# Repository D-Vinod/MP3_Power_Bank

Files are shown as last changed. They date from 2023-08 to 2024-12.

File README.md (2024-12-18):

# 🎵 MP3 Player Design Project

## 📝 Project Overview

This repository contains the design and implementation details of an **MP3 player with power bank functionality**, developed as part of the **EN2160 - Electronic Design Realization** course at the **University of Moratuwa**. The project incorporates multiple features including music playback from an SD card, volume control, an OLED display, and a high-capacity battery pack for extended use and device charging.

---

## 📌 Table of Contents

1. **[Introduction](#introduction)**
2. **[Design Specifications](#design-specifications)**
   - [Display](#display)
   - [Control IC](#control-ic)
   - [SD Card Storage](#sd-card-storage)
   - [Battery](#battery)
   - [Boost Converter](#boost-converter)
   - [Charging and Regulation Circuit](#charging-and-regulation-circuit)
3. **[Functionality Description](#functionality-description)**
4. **[PCB Design](#pcb-design)**
5. **[Components/BOM](#componentsbom)**
6. **[Enclosure Design](#enclosure-design)**
7. **[Soldering and Testing](#soldering-and-testing)**
8. **[Final Prototype](#final-prototype)**
9. **[Instruction to Use](#instruction-to-use)**
10. **[Appendices](#appendices)**
    - [Appendix I: BOM](#appendix-i-bom)
    - [Appendix II: Design Files](#appendix-ii-design-files)
    - [Appendix III: Final Product Assembly](#appendix-iii-final-product-assembly)
    - [Appendix IV: Display Code](#appendix-iv-display-code)
    - [Appendix V: Preliminary Design Approach](#appendix-v-preliminary-design-approach)

---

## 📄 Introduction

The MP3 player is designed to:

- Play music from an SD card.
- Output audio via a 3.5mm audio jack.
- Provide power bank functionality using a high-capacity battery pack.
- Include user controls and an OLED display for easy navigation.

---

## 🔧 Design Specifications

### Display

- **Type:** 0.96-inch OLED display  
- **Purpose:** Displays track number and volume level.

### Control IC

- **Microcontroller:** ATmega328p (SMD version)  
- **Features:** Supports display control and navigation buttons.

### SD Card Storage

- **Module:** DFPlayer Mini  
- **Functionality:** Decodes audio and outputs analog signals.

### Battery

- **Type:** Three 18650 Li-ion batteries (3600mAh each)  
- **Feature:** Provides extended music playback and power bank functionality.

### Boost Converter

- **Function:** Converts 3.7V to 5V for charging external devices.

### Charging and Regulation Circuit

- **Components:**  
  - **TC4056:** Charging management IC  
  - **DW01:** Battery protection IC  
  - **FS8205:** Dual MOSFET for efficient power switching

---

## ⚙️ Functionality Description

- **Inputs:**  
  - `Prev`: Go to the previous track  
  - `Next`: Go to the next track  
  - `Select`: Play/pause music and control volume  
- **Audio Output:** 3.5mm audio jack  
- **Power Bank:** Capable of charging external devices via USB.

---

## 🖨️ PCB Design

The design includes:

- **Power Management:** Handles battery charging and protection.
- **Control Circuit:** Manages user inputs and display output.
- **Audio Output:** Interfaces with the DFPlayer Mini for music playback.

---

## 📋 Components/BOM

A detailed **Bill of Materials (BOM)** is available in **[Appendix I](#appendix-i-bom)**.

---

## 🏗️ Enclosure Design

- **Software Used:** SolidWorks  
- **Design:** Two-part enclosure with lip and groove fitting and screw mounts.  
- **Features:** Openings for buttons, audio jack, SD card, and USB ports.

---

## 🔧 Soldering and Testing

- **Process:**  
  - Soldered SMD and through-hole components onto the PCB.  
  - Tested the power management and audio playback functionality.  
- **Issues:** Resolved overheating issues with the boost converter.

---

## ✅ Final Prototype

The final assembled prototype includes:

- MP3 player with OLED display.  
- High-capacity battery pack.  
- Enclosure with user-friendly controls.

---

## 📖 Instruction to Use

1. **First-Time Setup:** Connect to an external power source to reset the IC’s logic levels.
2. **Playback:** Insert an SD card with preloaded songs and use the buttons to navigate tracks.
3. **Charging:** Use the USB ports to charge external devices.

---

## 📎 Appendices

### Appendix I: BOM

Refer to the detailed **Bill of Materials (BOM)** for component specifications and costs.

### Appendix II: Design Files

Includes **schematics**, **PCB layouts**, and **fabrication files**.

### Appendix III: Final Product Assembly

Step-by-step assembly process with images of the prototype.

### Appendix IV: Display Code

Arduino code for controlling the OLED display and MP3 playback.

### Appendix V: Preliminary Design Approach

Initial sketches, design iterations, and user-centered design feedback.

---

## 🚀 Developed by

- **Bandara D.M.D.V.**  
  **University of Moratuwa**  
  **Department of Electronic & Telecommunication Engineering**  
  **July 14, 2023**

---

📂 **[Project Documentation and Design Files](#)**  
For detailed design files and schematics, explore the repository contents.

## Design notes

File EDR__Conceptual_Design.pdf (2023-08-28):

## Department of Electronic & Telecommunication Engineering Faculty of Engineering University of Moratuwa

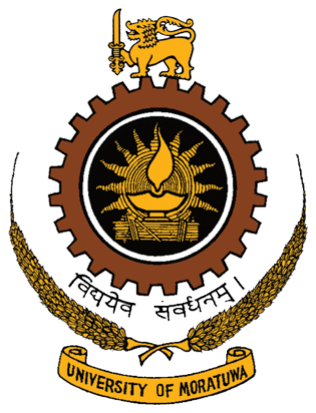
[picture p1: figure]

## Electronic Design Realization - MP3 Player

## Conceptual Design

Bandara D.M.D.V.

### Undergraduate (Biomedical engineering) Department Electronic and Telecommunications Faculty of Engineering University of Moratuwa

## June 1, 2023

## Contents

Proposed Design - Original Interpretation 1

Design-Driven Innovation
2
Design 1
| 2
Design 2
| 4
Design 3
| 5

User centered design
| 5
Design 4
| 7

Selection Matrix
| 8

Conclusion
| 10

I

## Proposed Design - Original Interpretation

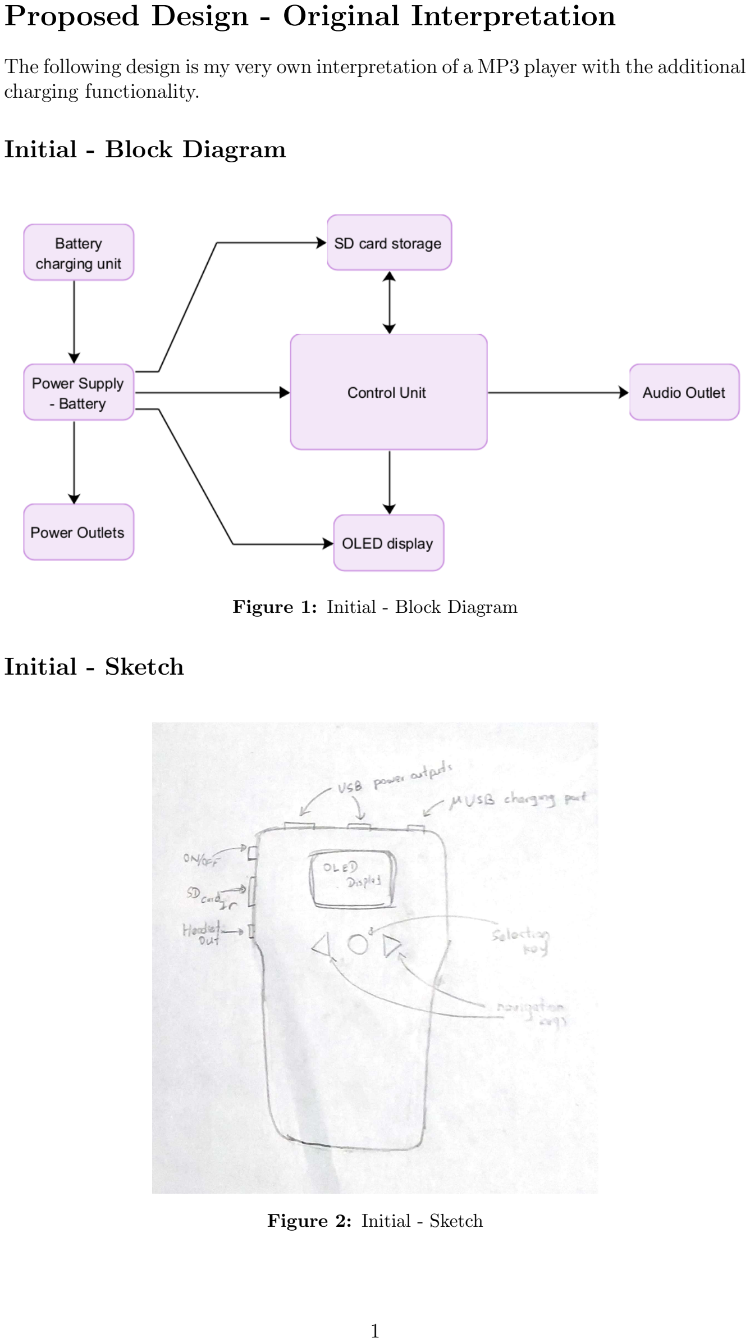
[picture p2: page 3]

The following design is my very own interpretation of a MP3 player with the additional charging functionality.

### Initial - Block Diagram

Figure 1: Initial - Block Diagram

### Initial - Sketch

Figure 2: Initial - Sketch

### Proposed Specifications

- 9600mAh battery can ensure a longer period of non-interrupted music.
- Songs are stored in a SD card storage.
- 3.5mm Headset Outlet is used to give Sound output.
- USB outlet to charge two devices at the same time.
- 3 Buttons to navigate through songs and control Volume
- OLED display to show the soundtrack number, Volume.
- Micro USB Inlet to recharge the device

Then this design was subjected to 3 iterations of design-driven innovation cycles which lead to 3 new designs which are included in this report. The group members who actively contributed to the design cycle are,

1. Bandara H.M.S.D. - 200064C
2. Chandira R.M. - 200082E
3. Hewavitharana M.I. - 200220D
4. Marasinghe M.M.H.N.B. - 200381U
5. Pramuditha A.A.H. - 200476P
6. Samarasekera A.M.P.S. - 200558U
7. Wijetunga W.L.N.K - 200733D

And together, we came up with the following three designs.

## Design-Driven Innovation

### Design 1

The first suggestion that everyone agreed upon was to change the traditional design of the enclosure. Disk shape was the one most agreed upon which allowed the design to be very thin and easy to carry( thin like a book ). Also, there is a slit to easily wind the earpiece wires and in the back a dent for the ends to be clipped in. I have to change to a thin LIPO battery to achieve these specifications.

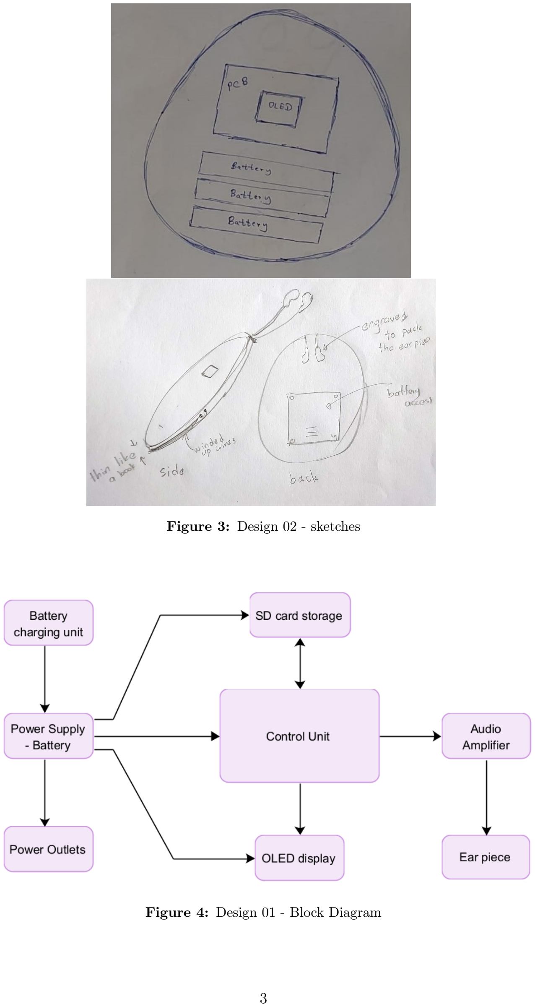
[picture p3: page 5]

Figure 3: Design 02 - sketches

Figure 4: Design 01 - Block Diagram

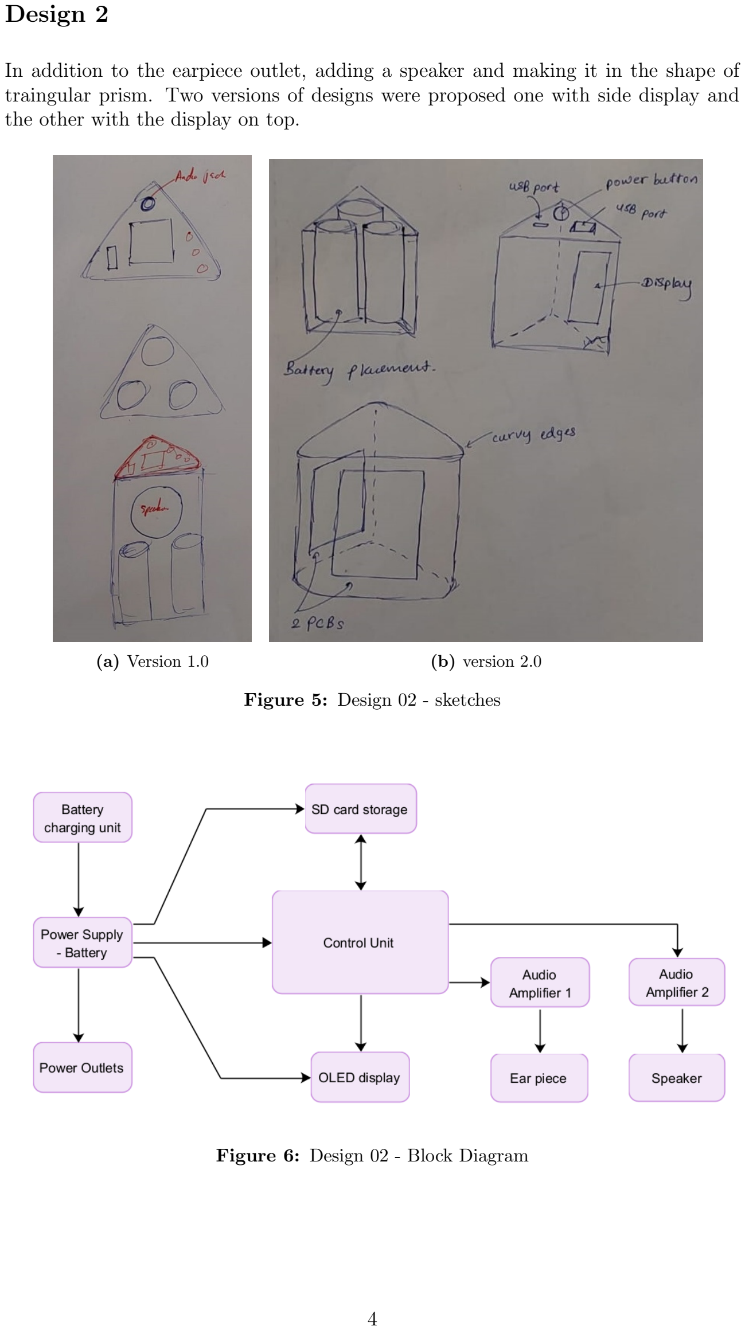
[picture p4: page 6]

### Design 2

In addition to the earpiece outlet, adding a speaker and making it in the shape of traingular prism. Two versions of designs were proposed one with side display and the other with the display on top.

(a) Version 1.0 | (b) version 2.0

Figure 5: Design 02 - sketches

Figure 6: Design 02 - Block Diagram

### Design 3

Similar in design to the original but with an inbuilt speaker, Bluetooth functionality, and velcro/clip-on method to easily attach it to the flaps of common bags. This design should be designed to play high-quality music through its in-built speakers.

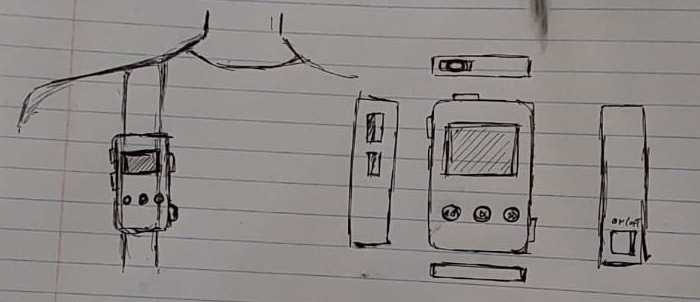
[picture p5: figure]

Figure 7: Design 03 - sketch

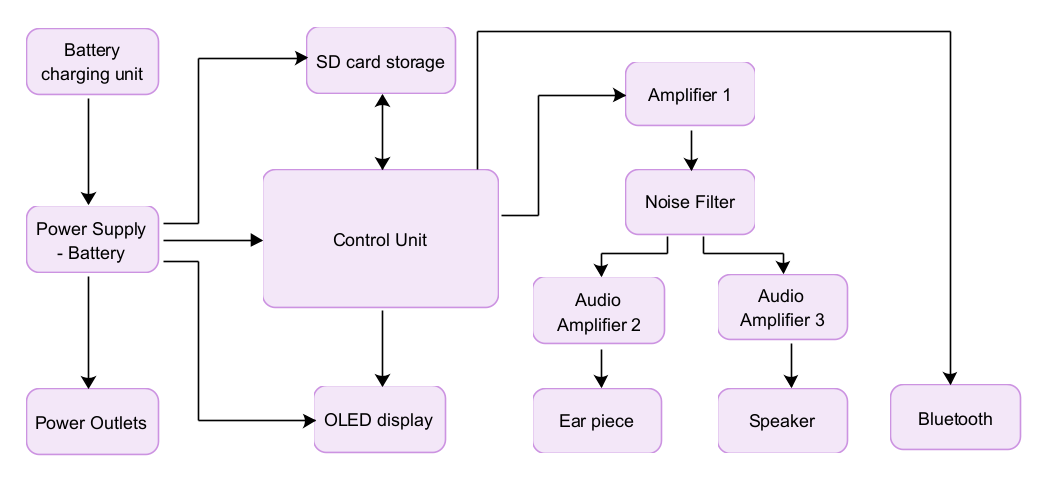
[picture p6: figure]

Figure 8: Design 03 - Block Diagram

## User-centered design

### User survey

With the initial design, we surveyed some of the other university undergraduates and outside personnel to get diverse user feedback and identify flows, and improvements they might expect. For this, we have created a questionnaire including the following questions.

### Questionnaire

1. Your current profession?
2. Will you use or need something like this?
3. At what price point would you like to buy such an item?
4. On a scale of 1-5, how would you rate our product considering other similar products in the market as the midline (Rating 3)
5. What other specifications would you like to add to this design? How can we make this to your likeness?
6. Any other comments on the Product?

We received seven such completed question sets within the allocated period of two hours and the results per each question are summarized below.

### User Feedback

1. Our sample of users included a businessman, a School student, a Construction worker, a factory worker, and three undergraduates and one of which was a part-time musician.
2. Most did say that their mobile can play music but since this has an extended battery life and also can charge your mobile phone we received sufficient constructive feedback about the idea.
3. The average scaled rating we got was 4.143 Which is satisfactory.
4. Improvement wise there are a few suggestions which we have used below to improve our device as shown below.
5. Few said that the Mp3 players are a bit outdated and not using them anymore. Hence the market will be low.

With the suggestion of our sample users, we have short-listed the specifications as follows.

### Selected specifications

- Bluetooth compatibility to transfer music and connect to wireless earbuds/ headphones
- Battery size can be reduced using a lipo battery and overlaying it with the circuit, hence the whole device size can be reduced.
- Build an inbuilt speaker with quality sounds
- Touch-screen to navigate the system menu.

### Rejected specifications

We had to reject a few of the user specifications as those are not necessary and are used by anyone in this kind of device.

- Using a portable USB stick to store songs in addition to the SD card storage.
- Radio functionality

### Design 4

Following the design cycle specified in the reference, we were able to come up with the following design with the additional features we mentioned above.

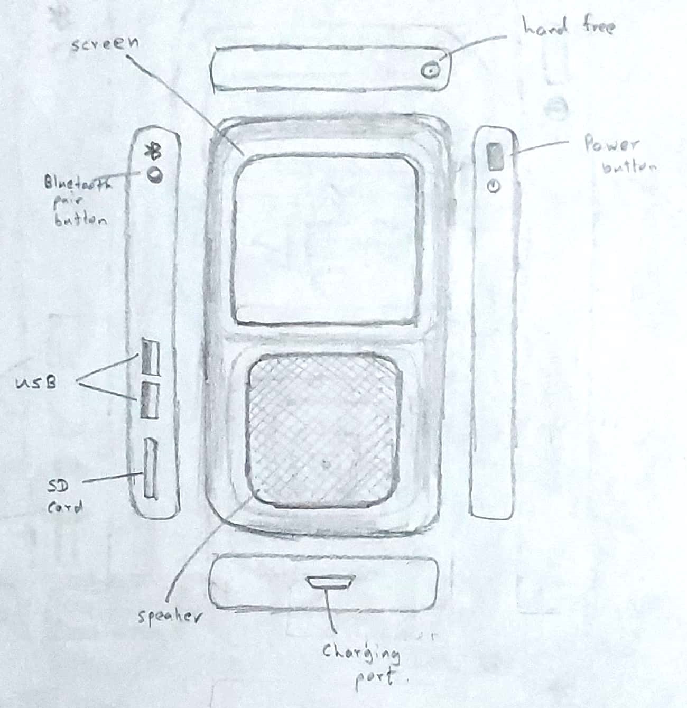
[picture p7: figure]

Figure 9: Design 04 - sketch

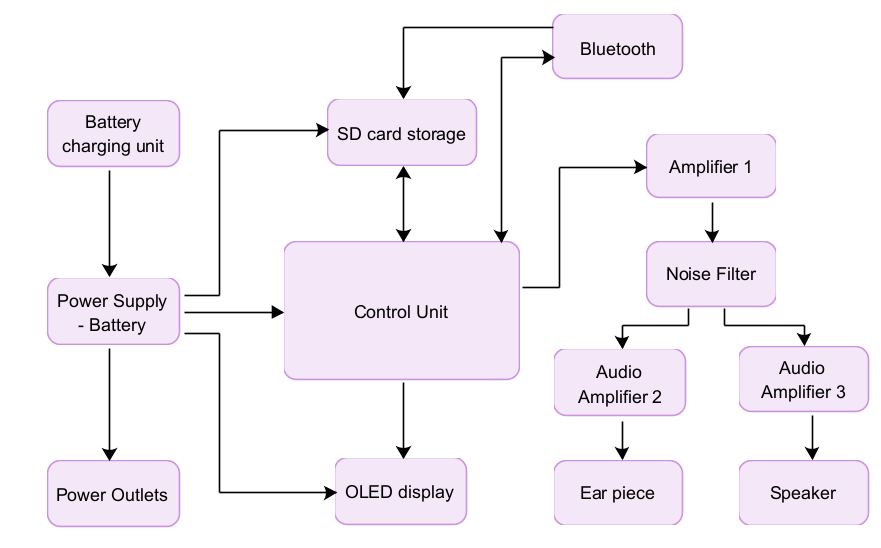
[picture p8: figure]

Figure 10: Design 04 - Block Diagram

## Selection Matrix

Taking the Initial Sketch as the Baseline ( 0 marks), the following matrix is used to select the best design.

### For Sketches

The criteria used for the selection of the best design sketch are,

1. Ergonomics - How well does the device fit in the user’s hand?
2. User Safety - Is it safe to use?
3. Durability - Is the design going to last a long time or will it break?
4. Accessibility - Is the design easy to use, and easy to control?
5. Weight and portability - Is the design easy to carry around?
6. Manufacturing cost - Will the design be cheap?
7. Overall look - IS the finishing look appealing to the majority of users?

Objectives | Weight | Design 01 | Design 02 | Design 03 | Design 04
Ergonomics | 5 | -1 | +1 | 0 | 0
User Safety | 10 | 0 | 0 | +1 | +1
Durability | 10 | -1 | +1 | -1 | -1
Accessibility | 7 | +1 | -1 | 0 | +1
Weight and portability | 10 | +1 | 0 | +1 | 0
Manufacturing Cost | 5 | -1 | -1 | 0 | -1
Overall look | 3 | -1 | +1 | +1 | +1
Final score - sketch | | -6 | 6 | 13 | 5

Table 1: Screening sketches

### For block diagrams

The criteria used for the selection of the best block diagram are,

1. Quality - Is the music quality better?
2. User-friendly interface - Is the user interface easy to use?
3. Functionality - Are the functions of the devices improved?
4. Accessories - Whether the supported amount of accessories such as headphones, and ear pieces have increased or not?
5. Manufacturing cost - Will the schematic design/parts be cheap?
6. Power efficiency - Will the battery last longer?
7. Scalability/Modularity - Will the design allow future improvements? Is it easy to replace certain parts separately?

Objectives | Weight | Design 01 | Design 02 | Design 03 | Design 04
Quality | 10 | 0 | 0 | +1 | +1
User-friendly interface | 5 | 0 | 0 | 0 | +1
Functionality | 10 | +0.25 | +0.5 | +0.5 | +1
Accessories | 5 | 0 | 0 | +1 | +1
Manufacturing cost | 4 | -1 | -1 | 0 | -1
Power efficiency | 8 | -1 | 0 | 0 | -1
Scalability/Modularity | 3 | 0 | 0 | 0 | -1
Final score - Block Diagram | | -9.5 | 1 | 20 | 15

Table 2: Screening block diagrams

Objectives | Design 01 | Design 02 | Design 03 | Design 04
Sketch | -6 | 6 | 13 | 5
Block diagrams | -9.5 | 1 | 20 | 15
Total score | -15.5 | 7 | 33 | 20

Table 3: Results

## Conclusion

In conclusion the best design from the design cycles is the design 03 given in Figure 7 And 8.

## Reference

- Article : Inclusive Design Toolkit ,Concept design process, University of Cambridge (http://www.inclusivedesigntoolkit.com/GS_overview/overview.html)

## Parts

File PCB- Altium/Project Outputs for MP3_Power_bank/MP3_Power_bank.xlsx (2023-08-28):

Line # | Name | Description | Designator | Revision ID | Revision State | Revision Status | Quantity | Manufacturer 1 | Manufacturer Part Number 1 | Manufacturer Lifecycle 1 | Supplier 1 | Supplier Part Number 1 | Supplier Unit Price 1 | Supplier Subtotal 1
 | 1k, 10K |  | 1K, R2, R3, R4, R5, R6 |  | Unknown server |  | 6 | Vishay | CRCW08050000Z0EA
 | ME2108 | 6.5V 400mA SOT-23(SOT-23-3) DC-DC Converters RoHS | B3 |  | Not managed |  | 1
 | 0.1u | Cap Ceramic 100nF 16V X7R ±5% Pad SMD 0603 +125°C T/R | C1 |  | Unknown server |  | 1 | Samsung | CL10B104JO8NNND | Volume Production
 | 0.1uF, 0.1u, 10uF | CAP CER 0.22UF 50V X7R 0805 | C2, C3, C4, C5 |  | Unknown server |  | 4 | Murata | GRM21BR71H224KA01L | Not Recommended for New Design
 | 0.1uF, 18pf | Chip Multilayer Ceramic Capacitors for General Purpose, 0805, 22uF, X5R, 15%, 20%, 6.3V | C6, C7, C8, C9 |  | Unknown server |  | 4 | Murata | GRM21BR60J226ME39L | Volume Production
 | 150080SS75000 | LED RED CLEAR 0805 SMD | D1, D2 |  | Unknown server |  | 2 | Wurth Electronics | 150080SS75000 | Volume Production
 | SS14 | DIODE SCHOTTKY 40V 1A DO214AC | D4 |  | Unknown server |  | 1 | Vishay Semiconductors | SS14-E3/61T
 | 105017-0001 | Micro-USB B Receptacle, Right Angle, Bottom Mount, Surface Mount, with Solder Tabs, -30 to 85 degC, 5-Pin USB, RoHS, Tape and Reel | J1 |  | Unknown server |  | 1 | Molex | 1050170001 |  | Mouser | 538-105017-0001 | 0.93 | 0.93
 | Battery, Vin, Output | CONN HEADER VERT 2POS 2.54MM | J2, J3, J5 |  | Unknown server |  | 3 | Harwin | M20-9990246 | Volume Production
 | 61300111121 | THT Vertical Pin Header WR-PHD, Pitch 2.54 mm, Single Row, 1 pins | J4, J11 |  | Not managed |  | 2
 | SW_Mp3_p, Mp3_p, Left, Select, Right | CONN HEADER VERT 2POS 2MM | J6, J12, J13, SW1, SW2, SW3 |  | Unknown server |  | 6 | Harwin | M22-2510205 |  | Mouser | 855-M22-2510205 | 0.2 | 1.2
 | OLED1 | Male Header, Pitch 2.54 mm, 1 x 4 Position, Height 10.03 mm, Tail Length 3.56 mm, RoHS, Bulk | J7 |  | Not managed |  | 1
 | 3.5 jack | 3.50mm (0.141", 1/8", Mini Plug) - Headphone Phone Jack Stereo (3 Conductor, TRS) Connector Solder | J8 |  | Not managed |  | 1
 | 22uH | Shielded Wirewound Inductor 22uH 20% 1.5A 0.1495Ω SMD | L1 |  | Unknown server |  | 1 | Taiyo Yuden | NR6045T220M | Volume Production
 | 61400416021 | USB 2.0 Type A Receptacle WR-COM, Horizontal, THT | O1, O2 |  | Not managed |  | 2
 | Program | Male Header, Pitch 2.54 mm, 1 x 5 Position, Height 10.03 mm, Tail Length 3.56 mm, -55 to 105 degC, RoHS, Bulk | P1 |  | Unknown server |  | 1 | TE Connectivity | 640456-5 | Volume Production
 | Control | Male Header, Pitch 2.54 mm, 1 x 3 Position, Height 8.38 mm, Tail Length 3.18 mm, RoHS, Bulk | P2 |  | Unknown server |  | 1 | Molex | 22-28-4033
 | TC4056A | Integrated Circuit | U1 |  | Not managed |  | 1
 | DW01A | Integrated Circuit | U2 |  | Not managed |  | 1
 | FS8205A | MOSFET (N-Channel) | U3 |  | Not managed |  | 1
 | DFR0299 | Dfplayer - a Mini Mp3 Player | U4 |  | Not managed |  | 1
 | DEV_pro mini |  | U5 |  | Not managed |  | 1
 | ATmega328P-AN | 8-bit AVR Microcontroller, 32KB Flash, 1KB EEPROM, 2KB SRAM, 32-pin TQFP, Industrial Grade (-40°C to 105°C) | U6 |  | Unknown server |  | 1 | Microchip | ATMEGA328P-AN | Volume Production
 | 16.000MHZ | Crystal or Oscillator | Y1 |  | Not managed |  | 1

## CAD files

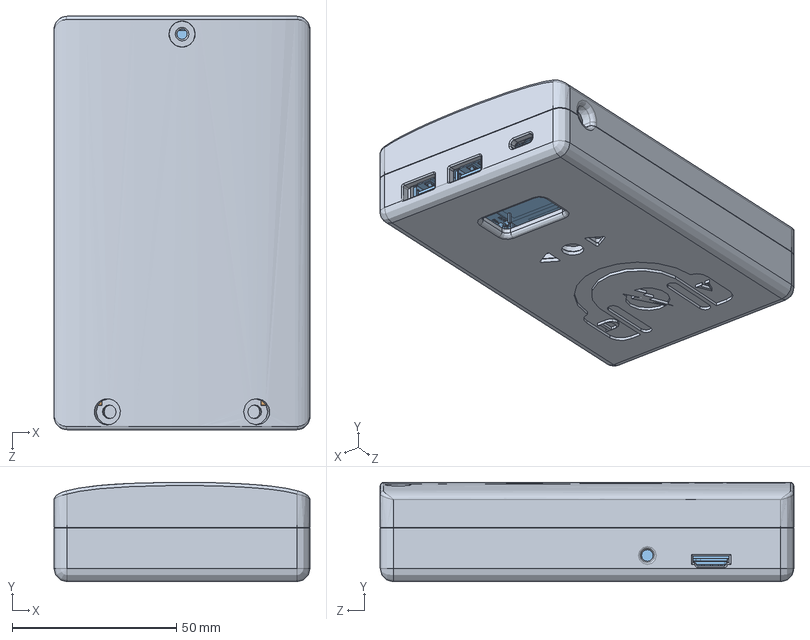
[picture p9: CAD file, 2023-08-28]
Enclosure - Solidwork/Assem1.SLDASM
78.0 x 30.3 x 126.0 mm
top
3Batteries
PCB1.step

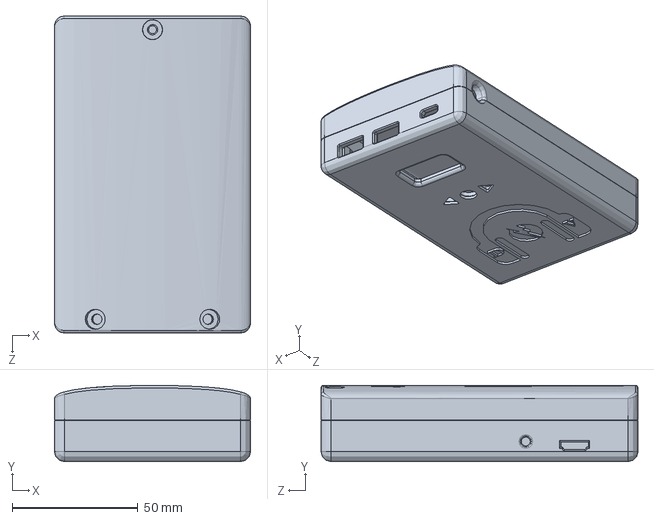
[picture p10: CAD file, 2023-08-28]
Enclosure - Solidwork/top.SLDPRT
78.0 x 30.3 x 126.0 mm

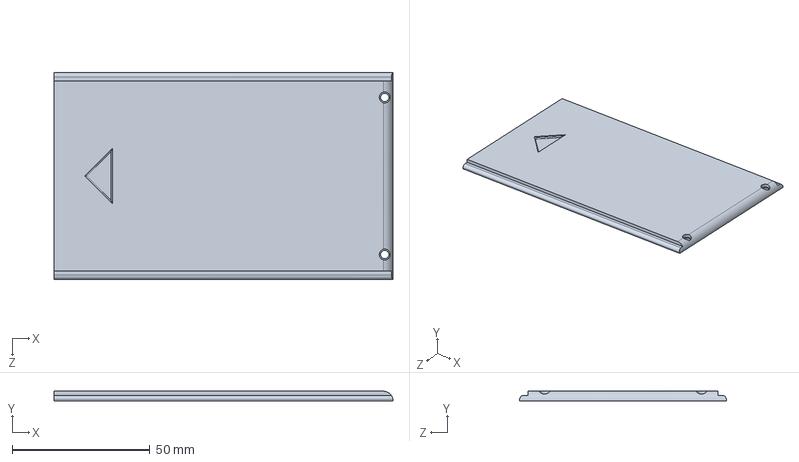
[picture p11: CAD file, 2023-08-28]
Enclosure - Solidwork/bottom.SLDPRT
123.0 x 3.50 x 75.0 mm

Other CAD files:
Enclosure - Solidwork/3Batteries.SLDPRT

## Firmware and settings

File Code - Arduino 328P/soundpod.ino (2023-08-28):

#include <Arduino.h>
#include <SoftwareSerial.h>
#include <DFRobotDFPlayerMini.h>
#include <U8g2lib.h>
#include <Wire.h>
#include <EEPROM.h>

SoftwareSerial customSoftwareSerial(12,13);
DFRobotDFPlayerMini myDFPlayer;

U8G2_SH1106_128X64_NONAME_F_HW_I2C u8g2(U8G2_R0, /* reset=*/ U8X8_PIN_NONE);

const uint8_t leftButton = 2;
const uint8_t selectionButton = 5;
const uint8_t rightButton = 3;

volatile uint8_t sMenuSelection = 2;
volatile uint8_t selection = 1;
volatile bool updateScreen = true;

boolean playing = false;
boolean inSideMenuSelection = true;

// Variables
uint8_t filecounts;                     // total number of files in current folder
uint8_t foldercounts;                   // total number of folders on sd-card

uint8_t volume = 20;                    // current volume (0 .. 30)
uint8_t folder = 1;                     // current sd-card folder
uint8_t file   = 1;                     // curent file in current folder
uint8_t eq = 0;

uint8_t batteryLevel = 0;
float resistor_ratio_factor = 3.91;
uint8_t mins = 0;
unsigned long lastTimepassed = 0;

void setup(void) {
    //Initializing u8g2 library
    Serial.begin(9200);
  u8g2.begin();  
  u8g2.firstPage(); 
  do{
    flashPage();    
  }while(u8g2.nextPage());
  pinMode(leftButton,INPUT_PULLUP);
  pinMode(rightButton,INPUT_PULLUP);
  pinMode(selectionButton,INPUT_PULLUP);
  
  attachInterrupt(digitalPinToInterrupt(leftButton),leftButtonISR, FALLING);
  attachInterrupt(digitalPinToInterrupt(rightButton),rightButtonISR, FALLING);
  
  //being hardware serial for debugging
  Serial.begin(9600);
  //Initializing software serial
  customSoftwareSerial.begin(9600);

  if (!myDFPlayer.begin(customSoftwareSerial)) {  //Use softwareSerial to communicate with mp3.
    Serial.println(F("Please insert the SD card!")); 
  }
  volume = EEPROM.read(0);
  if(volume > 30)
  volume = 30;
  
  eq     = EEPROM.read(1);
  if(eq > 5)
  eq = 5;
  
  file   = EEPROM.read(2);
  if(file >= 255)
  file = 1;
  
  delay(1000);
  myDFPlayer.volume(volume);  //Set volume value. From 0 to 30
  delay(500);
  foldercounts = myDFPlayer.readFolderCounts();
  startFolderPlay();
//  
}

void loop() {
  batteryReader();
//Selection button
  if(!digitalRead(selectionButton) && inSideMenuSelection)
  {
      inSideMenuSelection = false;
      updateScreen = true;
      delay(200);
  }
  else if(!digitalRead(selectionButton) && !inSideMenuSelection && sMenuSelection == 1)
  {
       if(selection == 1)
       {
        if(file > 1)
        {
         //previous audio
         myDFPlayer.previous();
         file--;
         if(!playing)
            playing = true;
         EEPROM.write(2, file);
        }
       }
       else if(selection == 2)
       {
         //pause / play
         if(playing)
         {
          myDFPlayer.pause();
         }
         else
         {
          myDFPlayer.start();
         }
         playing = !playing;
       }
       else if(selection == 3)
       {
          //next audio
          file++;
            myDFPlayer.next(); 
           if(!playing)
            playing = true;
            EEPROM.write(2, file);
       }
       else if(selection == 4)
       {
         //back to side menu
         selection = 1;
         inSideMenuSelection = true;
       }
       updateScreen = true;
       delay(200);
  }else if(!digitalRead(selectionButton) && !inSideMenuSelection && sMenuSelection == 2)
  {
     if(selection == 1)
     {
         selection = 2;
         myDFPlayer.volume(volume);
         EEPROM.write(0, volume);
     }
     else if(selection == 2)
     {
        selection = 4;
        myDFPlayer.EQ(eq);
        EEPROM.write(1, eq);
     }
     else if(selection == 4)
     {
         //back to side menu
         selection = 1;
         inSideMenuSelection = true;
     }
     updateScreen = true;
     delay(200);
  }

//Updating the dispaly
  if(updateScreen)
  {
    u8g2.firstPage();  
    do {
      int ch = (sMenuSelection);
      switch(ch){
          case 1:
            player();
            break;
          case 2:
            settings();
            break;
          default:
            Serial.println(F("Default Screen"));
        }
      updateScreen = false;
      }while ( u8g2.nextPage() );
  }

   // check player status
  if (myDFPlayer.available()) {
    uint8_t type = myDFPlayer.readType();
    int value = myDFPlayer.read();

    switch (type) {
      case DFPlayerPlayFinished:
        if (file < filecounts) {
          file++;
          myDFPlayer.playFolder(folder, file);
          EEPROM.write(2, file);
          updateScreen = true;
        }
        break;
      default:
        break;
    }
  } 
}
